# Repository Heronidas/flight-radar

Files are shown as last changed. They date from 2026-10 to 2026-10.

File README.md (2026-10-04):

# Flight Radar

ESP32 desk flight radar. A round GC9A01 display shows aircraft around a fixed location, a small SSD1306 OLED shows details of the selected aircraft, and a rotary encoder controls zoom, selection and OLED pages.

Aircraft positions come from the OpenSky Network API, aircraft types from hexdb.io.

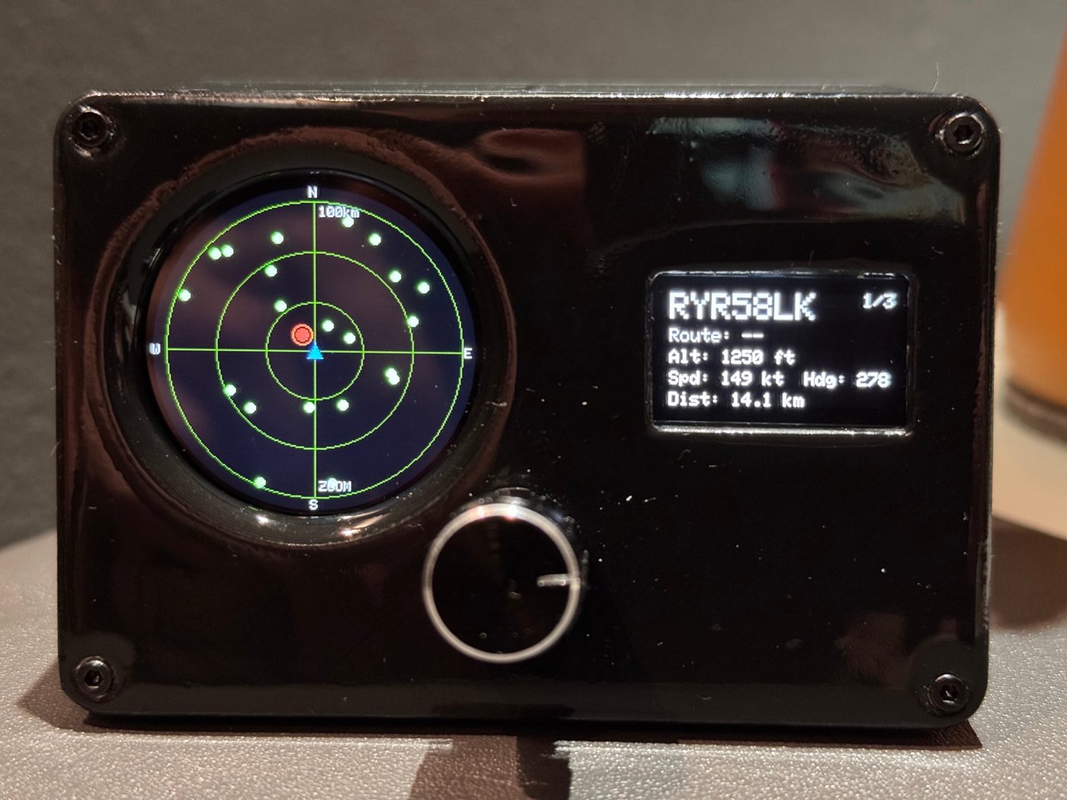
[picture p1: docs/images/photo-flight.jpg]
Flight page

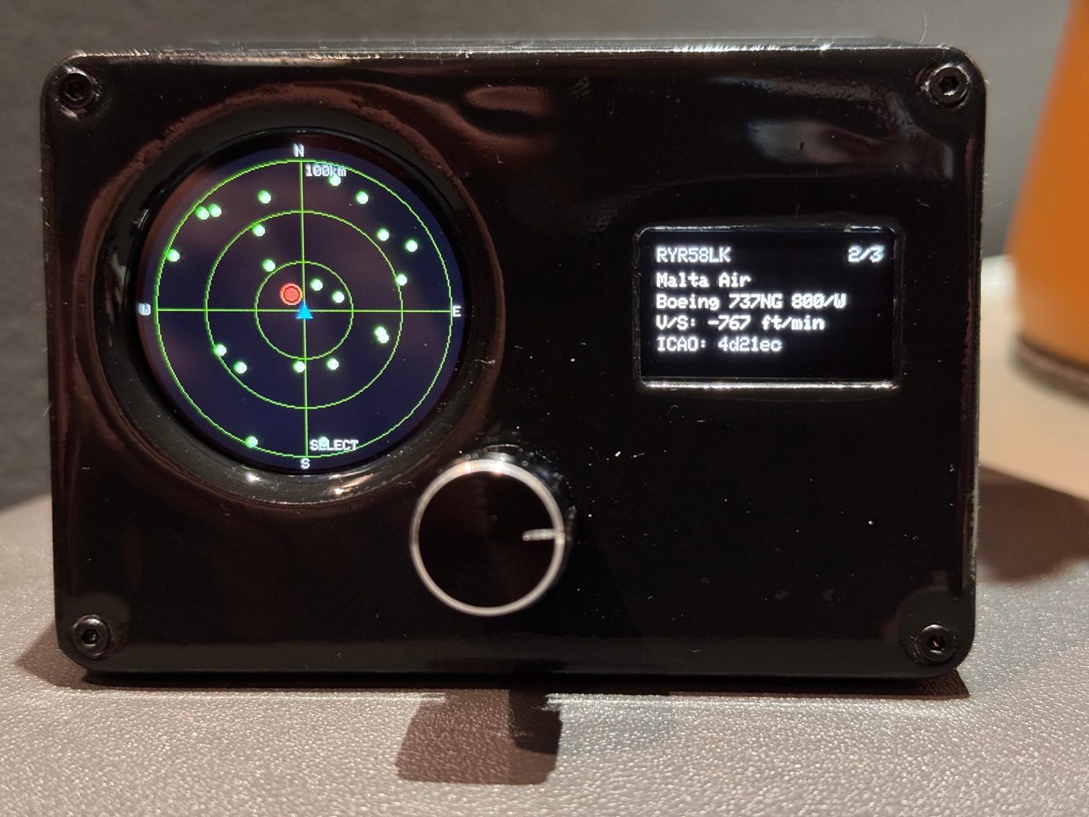
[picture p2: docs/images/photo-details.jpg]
Details page


## Hardware

- ESP32 DevKit (38 pin)
- GC9A01 1.28" round display, 240x240 (SPI)
- SSD1306 0.96" OLED, 128x64 (I2C, address 0x3C)
- EC11 rotary encoder with push button
- Regulated 5 V supply, at least 1 A
- Adhesive anti-slip pads, 10 mm diameter (underside)
- 4 × M2×8 screws and 4 × M2 heat-set inserts (case)

## Wiring

All parts run at 3.3 V. Power is fed directly to the ESP32 `5V` and `GND` pins; the enclosure has a snug cable pass-through. Disconnect the supply while flashing over USB.

| Part | Part pin | ESP32 pin |
|---|---|---|
| GC9A01 | VCC / GND | 3V3 / GND |
| | SCL (SCK) | GPIO18 |
| | SDA (MOSI) | GPIO23 |
| | CS | GPIO15 |
| | DC | GPIO2 |
| | RES | GPIO4 |
| | BLK | 3V3 |
| SSD1306 | VCC / GND | 3V3 / GND |
| | SDA | GPIO21 |
| | SCL | GPIO22 |
| EC11 | + / GND | 3V3 / GND |
| | CLK | GPIO25 |
| | DT | GPIO26 |
| | SW | GPIO27 |
| Power supply | +5 V / GND | 5V / GND |

GPIO2 and GPIO15 are strapping pins. If an upload fails, disconnect both wires briefly.

## Case

3D-printable enclosure: [`case/Flightradar_case.stl`](case/Flightradar_case.stl). Needed for the case:

- 4 × M2×8 screws
- 4 × M2 heat-set inserts
- Adhesive anti-slip pads, 10 mm diameter (optional, room on the underside)

Power: 5 V directly to the ESP32 `5V` and `GND` pins, with a snug cable pass-through.

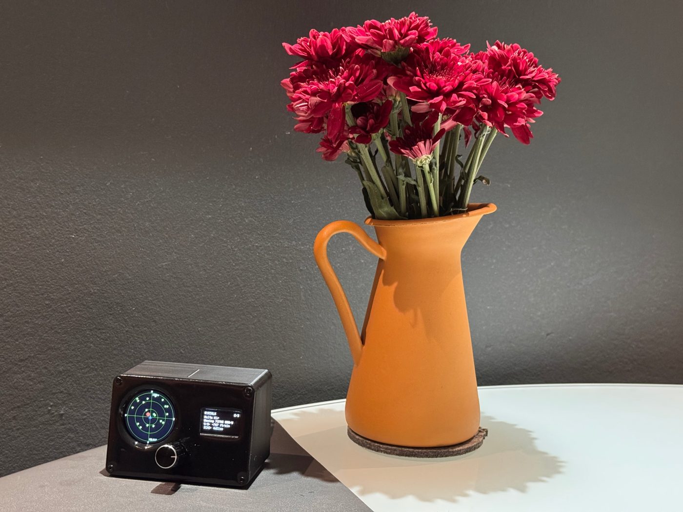
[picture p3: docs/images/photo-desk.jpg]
Finished device


## Setup

1. Install the ESP32 board package and select **ESP32 Dev Module**.
2. Install the libraries *Adafruit GFX Library*, *Adafruit SSD1306*, *GFX Library for Arduino* (by Moon On Our Nation) and *ArduinoJson*.
3. Upload `flight_radar/flight_radar.ino`. Nothing needs to be edited in the sketch.
4. On first start the device opens the WiFi **FlightRadar-Setup** (no password). Connect with a phone or PC and open `http://192.168.4.1`.
5. Select the WiFi network, enter the password and save. Only the WiFi is required. The device restarts and connects.
6. Open `http://flightradar.local/` (or the IP shown on the small display) and enter latitude, longitude, the OpenSky client ID and secret, and an OTA password. Until coordinates are set, the displays ask for them.

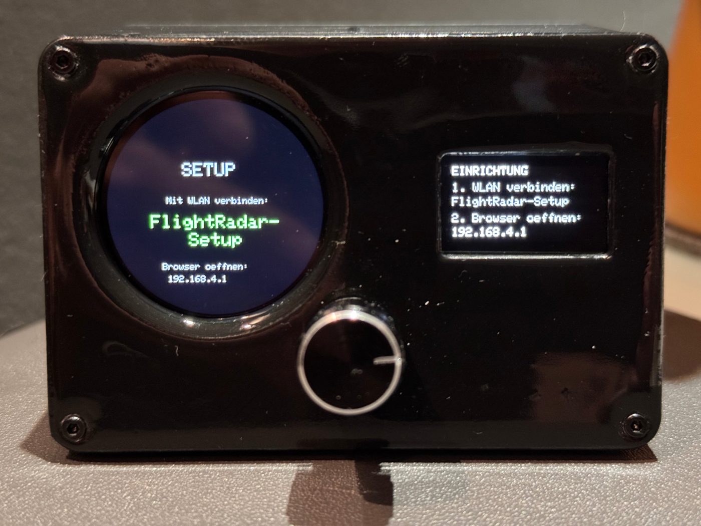
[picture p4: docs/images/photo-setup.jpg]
Setup screen


## OpenSky API

Aircraft data comes from the [OpenSky Network](https://opensky-network.org). Credentials are optional but recommended: anonymous access is limited to 400 credits per day, accounts get 4,000.

1. Create a free account at [opensky-network.org](https://opensky-network.org).
2. Open the [Account page](https://opensky-network.org/my-opensky/account) and create a new API client.
3. Copy the `client_id` and `client_secret` and paste them into the setup page.

Latitude and longitude: long-press the location in Google Maps, the coordinates appear at the top.

To change settings later, hold the encoder while powering on, or open `http://flightradar.local/` in the home network. Settings are stored in flash. If the saved WiFi cannot be reached, the setup portal opens and the device restarts after 10 minutes to try again.

## Updates (OTA)

Set an OTA password (at least 6 characters) on the setup page. Without a password, OTA is disabled. The first OTA-capable firmware must be flashed over USB.

- Arduino IDE: select the network port `flightradar` under *Tools > Port*, upload as usual and enter the OTA password.
- Browser: open `http://flightradar.local/update`, log in as `admin` with the OTA password and upload the `.bin` exported with *Sketch > Export Compiled Binary*.

If the sketch does not fit the update partition, select *Tools > Partition Scheme > Minimal SPIFFS (1.9MB APP with OTA)* and flash once over USB.

## Binaries

GitHub Actions compiles the sketch on every push (ESP32 Dev Module, partition scheme *Minimal SPIFFS*). The binaries are attached to the workflow run. Pushing a tag such as `v1.0.0` publishes them as a release:

- `*.merged.bin`: complete image for the first flash over USB (write at offset 0x0 with esptool or a browser flasher)
- `flight_radar.ino.bin`: application only, for OTA updates

## Controls

| Action | Effect |
|---|---|
| Turn (ZOOM) | Range: 10, 25, 50, 100 or 200 km |
| Short press | Next OLED page (1/3, 2/3, 3/3) |
| Turn (SELECT) | Select an aircraft (red) |
| Long press (~1 s) | Switch between ZOOM and SELECT |
| No input for 5 min | Screensaver: radar sweep with the aircraft in range, small display off. Any input wakes it. |
| Hold while powering on | Opens the setup portal |

The selection stays on the same aircraft between updates. Data is polled every 30 s and backs off for 3 minutes on HTTP 429.

## Notes

- The setup page and some OLED labels are in German.

## Guides

- [Guide (English)](docs/Flight_Radar_Guide_EN.pdf)
- [Anleitung (Deutsch)](docs/Flugradar_Anleitung_DE.pdf)

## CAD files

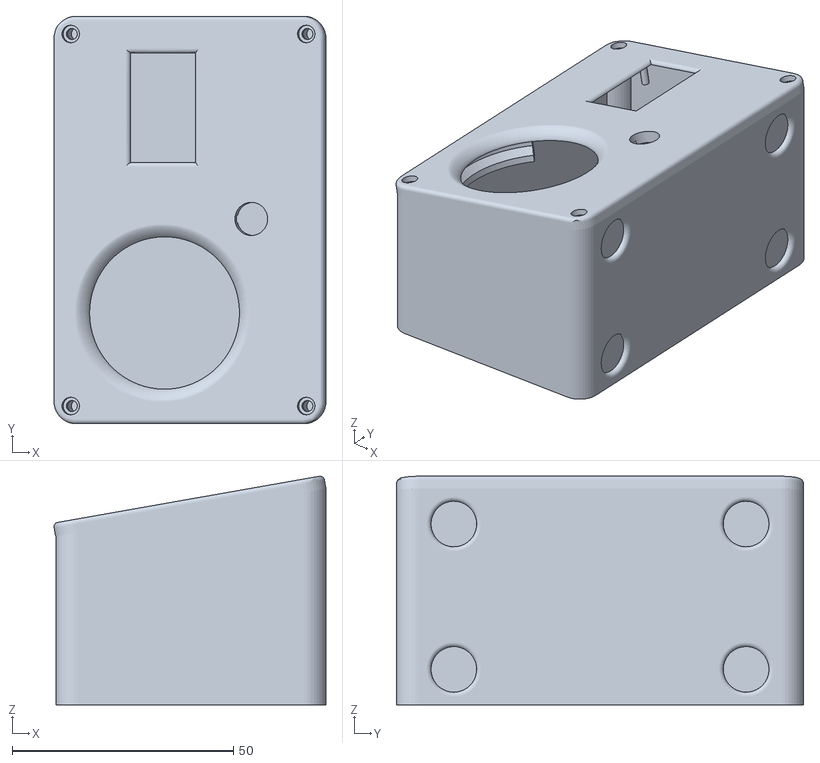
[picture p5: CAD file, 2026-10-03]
case/Flightradar_case.stl
61.4 x 92.0 x 51.6

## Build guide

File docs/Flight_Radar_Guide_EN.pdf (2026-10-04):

# Flight Radar – Operation

The device shows aircraft in the surrounding area. The round display is the radar; the small display shows details of the selected aircraft. Power on: connect the 5 V power supply. The radar appears after about 30 seconds.

### Controls (rotary encoder)

Action | Effect
Turn (display shows ZOOM) | Change range: 10, 25, 50, 100 or 200 km
Short press | Next page on the small display (1/3, 2/3, 3/3, then back to 1/3)
Turn (display shows SELECT) | Select an aircraft. The selected aircraft is marked red and its data appears on the small display.
Long press (about 1 second) | Switch between ZOOM and SELECT (shown at the bottom of the radar)
No input for 5 minutes | Screensaver (radar animation). Turning or pressing the encoder ends it.

### Procedure: selecting an aircraft

1. Press and hold the encoder – the bottom of the radar shows SELECT.
2. Turn the encoder until the desired aircraft is red.
3. If needed, press the encoder briefly to see more data.
The selection stays on the same aircraft between data updates.

### Display

Radar (round display) | Meaning
Blue triangle | Own location (center)
Green dot | Aircraft
Red dot with ring | Selected aircraft
Rings / number at top | Distance; the number applies to the outer ring
N, E, S, W | North, east, south, west
Small display | Content
Page 1/3 | Callsign, route (ICAO airports), altitude (ft), speed (kt), heading, distance
Page 2/3 | Operator, manufacturer and type, climb/descent rate (ft/min), ICAO address
Page 3/3 | IP address, aircraft within range and within 200 km, nearest aircraft, age of data

### Setup (first start, new WiFi or location)

1. On first start both displays show SETUP. To open setup later, hold the encoder pressed while powering on.
2. Connect a phone or PC to the WiFi FlightRadar-Setup (no password). Open 192.168.4.1 in the browser.

### 3. Select the WiFi network, enter the password and save. Only the WiFi is required. Enter

latitude/longitude and the OpenSky credentials (client ID, secret) later at flightradar.local.
4. Tap Save. The device restarts and shows the radar.
In the home network the page is also available at flightradar.local (or at the IP address on page 3/3).

### Notes

- Data updates every 30 seconds, so the dots move in steps. “No traffic” means no aircraft within the radius: select a larger range.
- If the device does not respond: unplug the power supply, wait 10 seconds, plug it in again. 1 ft = 0.30 m, 1 kt = 1.85 km/h. WiFi is required.

# ESP32 Pinout

ESP32 DevKit (38 pin, AZ-Delivery). Run all components at 3.3 V. Disconnect the ESP32 from power while wiring.
Component | Component pin | ESP32 pin | Done
Round display GC9A01 (SPI) | VCC | 3V3
| GND | GND
| SCL (SCK) | GPIO18
| SDA (MOSI) | GPIO23
| CS | GPIO15
| DC | GPIO2
| RES | GPIO4
| BLK | 3V3
OLED SSD1306 (I2C, 0x3C) | VCC | 3V3
| GND | GND
| SDA | GPIO21
| SCL | GPIO22
Rotary encoder EC11 | + | 3V3
| GND | GND
| CLK | GPIO25
| DT | GPIO26
| SW | GPIO27
Power supply 5 V DC | +5 V | 5V
| GND | GND

### Check by GPIO

GPIO | 2 | 4 | 15 | 18 | 21 | 22 | 23 | 25 | 26 | 27
Function | DC | RES | CS | SCK | SDA OLED | SCL OLED | MOSI | CLK | DT | SW

Used: GPIO 2, 4, 15, 18, 21, 22, 23, 25, 26, 27. The round display and the OLED share no pins.

### Firmware update (OTA)

1. Set an OTA password (at least 6 characters) on the setup page. Without a password, updates are disabled.
2. Arduino IDE: select the network port flightradar under Tools > Port, upload and enter the OTA password.
3. Or open flightradar.local/update in a browser (user admin, password = OTA password) and upload the .bin file (Sketch > Export Compiled Binary).
4. The small display shows the progress, then the device restarts.
The first OTA-capable firmware must be flashed over USB. If the sketch does not fit the update partition, select Tools > Partition Scheme > Minimal SPIFFS (1.9MB APP with OTA).

### Notes

- Power: regulated 5 V supply (at least 1 A) to the 5V and GND pins of the ESP32. Disconnect it while flashing over USB.
- Underside: space for adhesive anti-slip pads, 10 mm diameter.
- GPIO2 (DC) and GPIO15 (CS) are strapping pins. If the upload fails, briefly disconnect both wires.
- BLK is tied to 3V3 (GPIO21 is used for the OLED SDA).
- OLED stays dark and the monitor prints “SSD1306 init failed”: check SDA/SCL, change 0x3C to 0x3D in the sketch.
- If one detent of the encoder skips two steps: in handleEncoder() change the threshold 4 to 2.
- Settings are entered on the setup page; nothing to edit in the sketch. Serial Monitor: 115200 baud.

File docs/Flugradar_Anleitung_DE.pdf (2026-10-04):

# Flugradar – Bedienung

Das Gerät zeigt Flugzeuge in der Umgebung. Das runde Display ist das Radar, das kleine Display zeigt Details zum ausgewählten Flugzeug. Einschalten: 5-V-Netzteil anschließen, nach ca. 30 Sekunden erscheint das Radar.

### Bedienung mit dem Drehregler

Aktion | Wirkung
Drehen (Anzeige ZOOM) | Radius ändern: 10, 25, 50, 100 oder 200 km
Kurz drücken | Nächste Seite auf dem kleinen Display (1/3, 2/3, 3/3, dann wieder 1/3)
Drehen (Anzeige SELECT) | Flugzeug auswählen. Das ausgewählte Flugzeug ist rot markiert, seine Daten erscheinen auf dem kleinen Display.
Lang drücken (ca. 1 Sekunde) | Wechsel zwischen ZOOM und SELECT (Anzeige unten im Radar)
5 Minuten keine Eingabe | Bildschirmschoner (Radar-Animation). Knopf drehen oder drücken beendet ihn.

### Ablauf: Flugzeug auswählen

1. Regler lang drücken – unten steht SELECT.
2. Regler drehen, bis das gewünschte Flugzeug rot ist.
3. Bei Bedarf Regler kurz drücken, um weitere Daten zu sehen.
Die Auswahl bleibt bei der automatischen Aktualisierung auf demselben Flugzeug.

### Anzeige

Radar (rundes Display) | Bedeutung
Blaues Dreieck | Eigener Standort (Mitte)
Grüner Punkt | Flugzeug
Roter Punkt mit Ring | Ausgewähltes Flugzeug
Ringe / Zahl oben | Entfernung; die Zahl gilt für den äußeren Ring
N, E, S, W | Norden, Osten, Süden, Westen
Kleines Display | Inhalt
Seite 1/3 | Flugnummer, Route, Höhe (ft), Tempo (kt), Kurs, Entfernung
Seite 2/3 | Betreiber, Hersteller und Typ, Steig-/Sinkrate (ft/min), ICAO-Kennung
Seite 3/3 | IP-Adresse, Anzahl Flugzeuge im Radius und im Umkreis von 200 km, nächstes Flugzeug, Alter der Daten

### Einrichtung (Erststart, neues WLAN oder neuer Standort)

### 1. Beim ersten Start zeigen beide Displays SETUP bzw. EINRICHTUNG. Später öffnet man die

Einrichtung, indem man beim Einschalten den Regler gedrückt hält.

### 2. Handy oder PC mit dem WLAN FlightRadar-Setup verbinden (ohne Passwort). Im Browser

192.168.4.1 aufrufen.
3. WLAN-Netzwerk auswählen, Passwort eingeben, speichern. Nur das WLAN ist Pflicht. Breiten-/Längengrad und OpenSky-Zugang (Client-ID, Secret) später unter flightradar.local eintragen.
4. Speichern antippen. Das Gerät startet neu und zeigt das Radar.
Im Heimnetz ist die Seite auch unter flightradar.local erreichbar (oder über die IP-Adresse auf Seite 3/3).

### Hinweise

- Die Daten werden alle 30 Sekunden aktualisiert, die Punkte bewegen sich daher in Schritten. Steht „No traffic“ auf dem kleinen Display, ist kein Flugzeug im Radius: größeren Radius wählen.
- Reagiert das Gerät nicht: Netzteil abziehen, 10 Sekunden warten, wieder anschließen. 1 ft = 0,30 m, 1 kt = 1,85 km/h. Das Gerät benötigt WLAN.

# Pinbelegung ESP32

ESP32 DevKit (38 Pin, AZ-Delivery). Alle Bauteile mit 3,3 V betreiben. Beim Verkabeln den ESP32 vom Strom trennen.
Bauteil | Pin am Bauteil | Pin am ESP32 | Fertig
Rundes Display GC9A01 (SPI) | VCC | 3V3
| GND | GND
| SCL (SCK) | GPIO18
| SDA (MOSI) | GPIO23
| CS | GPIO15
| DC | GPIO2
| RES | GPIO4
| BLK | 3V3
OLED SSD1306 (I2C, 0x3C) | VCC | 3V3
| GND | GND
| SDA | GPIO21
| SCL | GPIO22
Drehregler EC11 | + | 3V3
| GND | GND
| CLK | GPIO25
| DT | GPIO26
| SW | GPIO27
Stromversorgung 5 V DC | +5 V | 5V
| GND | GND

### Kontrolle nach GPIO

GPIO | 2 | 4 | 15 | 18 | 21 | 22 | 23 | 25 | 26 | 27
Funktion | DC | RES | CS | SCK | SDA OLED | SCL OLED | MOSI | CLK | DT | SW

Belegt: GPIO 2, 4, 15, 18, 21, 22, 23, 25, 26, 27. Display-Anschlüsse und OLED teilen keine Pins.

### Firmware-Update (OTA)

1. Auf der Einrichtungsseite ein OTA-Passwort (mindestens 6 Zeichen) setzen. Ohne Passwort sind Updates ausgeschaltet.
2. Arduino IDE: unter Werkzeuge > Port den Netzwerk-Port flightradar wählen, hochladen und das OTA-Passwort eingeben.
3. Oder im Browser flightradar.local/update öffnen (Benutzer admin, Passwort = OTA-Passwort) und die .bin-Datei hochladen (Sketch > Kompilierte Binärdatei exportieren).
4. Das kleine Display zeigt den Fortschritt, danach startet das Gerät neu.
Die erste OTA-fähige Firmware muss per USB geflasht werden. Passt der Sketch nicht in den Update-Speicher: Werkzeuge > Partition Scheme > Minimal SPIFFS (1.9MB APP with OTA).

### Hinweise

- Stromversorgung: stabilisiertes 5-V-Netzteil (mind. 1 A) an 5V und GND. Beim USB-Flashen abziehen.
- Unterseite: Platz für rutschfeste Klebepads, Durchmesser 10 mm.
- GPIO2 (DC) und GPIO15 (CS) sind Strapping-Pins. Bricht der Upload ab, beide Leitungen kurz abziehen.
- BLK liegt fest an 3V3 (GPIO21 ist für SDA des OLED belegt).
- OLED bleibt dunkel, Monitor meldet „SSD1306 init failed“: SDA/SCL prüfen, im Sketch 0x3C auf 0x3D ändern.
- Springt ein Rastpunkt am Regler um zwei Stufen: in handleEncoder() die Schwelle 4 auf 2 setzen.
- Einstellungen nur über die Einrichtungsseite. Serial Monitor: 115200 Baud.

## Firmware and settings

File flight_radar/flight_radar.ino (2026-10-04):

/*
  ESP32 flight radar: GC9A01 round display, SSD1306 OLED, EC11 encoder.
  Data: OpenSky Network API, type lookup via hexdb.io.
  Settings are entered on the setup page (AP "FlightRadar-Setup" or http://flightradar.local/).
*/

#include <WiFi.h>
#include <WiFiClientSecure.h>
#include <HTTPClient.h>
#include <WebServer.h>
#include <ESPmDNS.h>
#include <Preferences.h>
#include <ArduinoOTA.h>
#include <Update.h>
#include <ArduinoJson.h>
#include <Wire.h>
#include <Adafruit_GFX.h>
#include <Adafruit_SSD1306.h>
#include <Arduino_GFX_Library.h>
#include <math.h>

const char *SETUP_AP_NAME   = "FlightRadar-Setup";
const char *MDNS_NAME = "flightradar";

const unsigned long POLL_INTERVAL_MS   = 30000;
const unsigned long BACKOFF_429_MS     = 180000;
const unsigned long LONG_PRESS_MS      = 700;
const unsigned long WIFI_TIMEOUT_MS    = 20000;
const unsigned long PORTAL_TIMEOUT_MS  = 600000;
const unsigned long SCREENSAVER_MS     = 300000;

#define TFT_CS   15
#define TFT_DC   2
#define TFT_RST  4
#define TFT_SCK  18
#define TFT_MOSI 23

#define ENC_CLK 25
#define ENC_DT  26
#define ENC_SW  27

WiFiClientSecure secureClient;

Adafruit_SSD1306 infoDisplay(128, 64, &Wire, -1);

Arduino_DataBus *bus = new Arduino_ESP32SPI(
    TFT_DC, TFT_CS, TFT_SCK, TFT_MOSI, GFX_NOT_DEFINED, VSPI);
Arduino_GFX *radar = new Arduino_GC9A01(bus, TFT_RST, 0, true);

#define RADAR_W 240
#define RADAR_H 240
#define RADAR_CX 120
#define RADAR_CY 120
#define RADAR_MAX_R 110

uint16_t COL_BG, COL_RING, COL_TEXT, COL_PLANE, COL_SELECTED, COL_HOME;

struct Plane {
  char icao24[7];
  char callsign[9];
  float altitude_m;
  float velocity_ms;
  float heading_deg;
  float vrate_ms;
  float distance_km;
  float bearing_deg;
};

#define MAX_PLANES 100
Plane planes[MAX_PLANES];
int planeCount = 0;
int visibleCount = 0;

enum Mode { MODE_ZOOM, MODE_SELECT };
Mode currentMode = MODE_ZOOM;

const int RANGE_PRESETS[] = {10, 25, 50, 100, 200};
const int NUM_RANGES = 5;
int rangeIndex = 3;

int selectedIndex = 0;
String selectedIcao = "";
bool followNearest = true;

int infoPage = 0;

unsigned long pollIntervalMs = POLL_INTERVAL_MS;
unsigned long lastFetchOkMs = 0;
int lastHttpCode = 0;

Preferences prefs;
String cfgSsid, cfgPass, cfgClientId, cfgClientSecret, cfgOtaPass;
double cfgLat = 0, cfgLon = 0;

void loadConfig() {
  prefs.begin("radar", true);
  cfgSsid         = prefs.getString("ssid", "");
  cfgPass         = prefs.getString("pass", "");
  cfgClientId     = prefs.getString("cid", "");
  cfgClientSecret = prefs.getString("csec", "");
  cfgOtaPass      = prefs.getString("ota", "");
  cfgLat          = prefs.getDouble("lat", 0);
  cfgLon          = prefs.getDouble("lon", 0);
  int r           = prefs.getInt("range", 3);
  rangeIndex      = (r < 0 || r >= NUM_RANGES) ? 3 : r;
  prefs.end();
}

bool hasConfig() {
  return cfgSsid.length() > 0;
}

bool hasCoords() {
  return !(cfgLat == 0 && cfgLon == 0);
}

volatile int encoderDelta = 0;
volatile uint8_t encoderStateHistory = 0;
volatile int8_t encoderAccum = 0;

const int8_t QUADRATURE_TABLE[16] = {
   0, -1,  1,  0,
   1,  0,  0, -1,
  -1,  0,  0,  1,
   0,  1, -1,  0
};

void IRAM_ATTR handleEncoder() {
  encoderStateHistory <<= 2;
  encoderStateHistory |= (digitalRead(ENC_CLK) << 1) | digitalRead(ENC_DT);
  encoderStateHistory &= 0x0F;

  int8_t change = QUADRATURE_TABLE[encoderStateHistory];
  if (change != 0) {
    encoderAccum += change;
    if (encoderAccum >= 4) {
      encoderDelta++;
      encoderAccum = 0;
    } else if (encoderAccum <= -4) {
      encoderDelta--;
      encoderAccum = 0;
    }
  }
}

bool btnActivity = false;
unsigned long lastActivityMs = 0;
bool btnWasDown = false;
bool longPressDone = false;
unsigned long btnDownMs = 0;
unsigned long btnEdgeMs = 0;

bool checkButton() {
  unsigned long now = millis();
  bool down = (digitalRead(ENC_SW) == LOW);
  bool changed = false;

  if (down != btnWasDown && now - btnEdgeMs > 25) {
    btnEdgeMs = now;
    btnWasDown = down;
    btnActivity = true;
    if (down) {
      btnDownMs = now;
      longPressDone = false;
    } else if (!longPressDone) {
      infoPage = (infoPage + 1) % 3;
      changed = true;
    }
  }

  if (btnWasDown && !longPressDone && now - btnDownMs > LONG_PRESS_MS) {
    longPressDone = true;
    currentMode = (currentMode == MODE_ZOOM) ? MODE_SELECT : MODE_ZOOM;
    changed = true;
  }
  return changed;
}

double toRad(double deg) { return deg * M_PI / 180.0; }
double toDeg(double rad) { return rad * 180.0 / M_PI; }

float distanceKm(double lat1, double lon1, double lat2, double lon2) {
  double R = 6371.0;
  double dLat = toRad(lat2 - lat1);
  double dLon = toRad(lon2 - lon1);
  double a = sin(dLat / 2) * sin(dLat / 2) +
             cos(toRad(lat1)) * cos(toRad(lat2)) *
             sin(dLon / 2) * sin(dLon / 2);
  double c = 2 * atan2(sqrt(a), sqrt(1 - a));
  return (float)(R * c);
}

float bearingDeg(double lat1, double lon1, double lat2, double lon2) {
  double y = sin(toRad(lon2 - lon1)) * cos(toRad(lat2));
  double x = cos(toRad(lat1)) * sin(toRad(lat2)) -
             sin(toRad(lat1)) * cos(toRad(lat2)) * cos(toRad(lon2 - lon1));
  double brng = toDeg(atan2(y, x));
  return (float)fmod((brng + 360.0), 360.0);
}

void syncSelection() {
  if (planeCount == 0) {
    selectedIndex = 0;
    return;
  }
  if (followNearest) {
    selectedIndex = 0;
  } else {
    int found = -1;
    for (int i = 0; i < planeCount; i++) {
      if (selectedIcao == planes[i].icao24) { found = i; break; }
    }
    selectedIndex = (found >= 0) ? found : 0;
  }
  if (selectedIndex >= visibleCount) selectedIndex = 0;
  selectedIcao = planes[selectedIndex].icao24;
}

void updateVisible() {
  int rangeKm = RANGE_PRESETS[rangeIndex];
  visibleCount = 0;
  while (visibleCount < planeCount && planes[visibleCount].distance_km <= rangeKm) {
    visibleCount++;
  }
  syncSelection();
}

String metaIcao24;
String metaType;
String metaManufacturer;
String metaOperator;
bool metaValid = false;
bool metaLookupFailed = false;

void lookupAircraftType(const String &icao24) {
  if (icao24.length() == 0) return;
  if (icao24 == metaIcao24 && (metaValid || metaLookupFailed)) return;
  if (WiFi.status() != WL_CONNECTED) return;

  HTTPClient http;
  http.setReuse(false);
  http.begin(secureClient, "https://hexdb.io/api/v1/aircraft/" + icao24);
  http.setTimeout(5000);
  int code = http.GET();

  metaIcao24 = icao24;
  metaValid = false;
  metaLookupFailed = true;

  if (code == 200) {
    String payload = http.getString();
    StaticJsonDocument<512> doc;
    if (!deserializeJson(doc, payload)) {
      if (doc.containsKey("Manufacturer")) {
        metaManufacturer = doc["Manufacturer"].as<String>();
        metaType = doc["Type"].as<String>();
        metaOperator = doc["RegisteredOwners"] | "";
        metaValid = true;
        metaLookupFailed = false;
      }
    }
  }
  http.end();
}

char routeCallsign[9] = "";
char routeText[24] = "";
bool routeDone = false;

struct AirportCode { char icao[5]; char iata[4]; };
AirportCode airportCache[12];
int airportCacheNext = 0;

const char *iataFor(const char *icao) {
  for (auto &a : airportCache) {
    if (strcmp(a.icao, icao) == 0) return a.iata;
  }
  AirportCode &slot = airportCache[airportCacheNext];
  airportCacheNext = (airportCacheNext + 1) % 12;
  strlcpy(slot.icao, icao, sizeof(slot.icao));
  strlcpy(slot.iata, icao + 1, sizeof(slot.iata));

  HTTPClient http;
  http.setReuse(false);
  http.begin(secureClient, "https://hexdb.io/api/v1/airport/icao/" + String(icao));
  http.setTimeout(5000);
  if (http.GET() == 200) {
    StaticJsonDocument<384> doc;
    if (!deserializeJson(doc, http.getString())) {
      const char *iata = doc["iata"] | "";
      if (iata[0]) strlcpy(slot.iata, iata, sizeof(slot.iata));
    }
  }
  http.end();
  return slot.iata;
}

void lookupRoute(const char *callsign) {
  if (!callsign[0]) return;
  if (routeDone && strcmp(callsign, routeCallsign) == 0) return;
  if (WiFi.status() != WL_CONNECTED) return;

  strlcpy(routeCallsign, callsign, sizeof(routeCallsign));
  routeText[0] = 0;
  routeDone = true;

  HTTPClient http;
  http.setReuse(false);
  http.begin(secureClient, "https://hexdb.io/api/v1/route/icao/" + String(callsign));
  http.setTimeout(5000);
  char icaoRoute[24] = "";
  if (http.GET() == 200) {
    StaticJsonDocument<256> doc;
    if (!deserializeJson(doc, http.getString())) {
      strlcpy(icaoRoute, doc["route"] | "", sizeof(icaoRoute));
    }
  }
  http.end();

  char *save;
  for (char *code = strtok_r(icaoRoute, "-", &save); code; code = strtok_r(nullptr, "-", &save)) {
    if (strlen(code) != 4) continue;
    if (routeText[0]) strlcat(routeText, ">", sizeof(routeText));
    strlcat(routeText, iataFor(code), sizeof(routeText));
  }
}

String openskyToken;
unsigned long tokenExpiresAtMs = 0;

String getOpenSkyToken() {
  if (cfgClientId.length() == 0 || cfgClientSecret.length() == 0) return "";
  if (openskyToken.length() > 0 && millis() < tokenExpiresAtMs) {
    return openskyToken;
  }
  if (WiFi.status() != WL_CONNECTED) return "";

  HTTPClient http;
  http.setReuse(false);
  http.begin(secureClient, "https://auth.opensky-network.org/auth/realms/opensky-network/protocol/openid-connect/token");
  http.addHeader("Content-Type", "application/x-www-form-urlencoded");

  String body = "grant_type=client_credentials&client_id=" + cfgClientId +
                "&client_secret=" + cfgClientSecret;

  int code = http.POST(body);
  if (code == 200) {
    String payload = http.getString();
    StaticJsonDocument<1024> doc;
    if (!deserializeJson(doc, payload)) {
      openskyToken = doc["access_token"].as<String>();
      long expiresIn = doc["expires_in"] | 1800;
      if (expiresIn < 120) expiresIn = 120;
      tokenExpiresAtMs = millis() + (unsigned long)(expiresIn - 60) * 1000UL;
      Serial.println("OpenSky token refreshed OK");
    }
  } else {
    Serial.print("Token fetch failed, HTTP code: ");
    Serial.println(code);
    openskyToken = "";
  }
  http.end();
  return openskyToken;
}

int doStatesRequest(HTTPClient &http, const String &url, const String &token) {
  http.setReuse(false);
  http.useHTTP10(true);
  http.begin(secureClient, url);
  http.setTimeout(15000);
  if (token.length() > 0) {
    http.addHeader("Authorization", "Bearer " + token);
  }
  return http.GET();
}

void fetchPlanes() {
  if (WiFi.status() != WL_CONNECTED) return;

  int rangeKm = RANGE_PRESETS[NUM_RANGES - 1];
  double latPad = rangeKm / 111.0;
  double lonPad = rangeKm / (111.0 * cos(toRad(cfgLat)) + 0.0001);

  String url = "https://opensky-network.org/api/states/all?lamin=" + String(cfgLat - latPad, 4) +
               "&lomin=" + String(cfgLon - lonPad, 4) +
               "&lamax=" + String(cfgLat + latPad, 4) +
               "&lomax=" + String(cfgLon + lonPad, 4);

  String token = getOpenSkyToken();

  HTTPClient http;
  int code = doStatesRequest(http, url, token);
  Serial.print("States fetch HTTP code: ");
  Serial.println(code);
  Serial.print("Free heap: ");
  Serial.println(ESP.getFreeHeap());

  lastHttpCode = code;

  if (code == 429) {
    Serial.println("Rate limited, backing off");
    pollIntervalMs = BACKOFF_429_MS;
    http.end();
    return;
  }

  if (code != 200) {
    http.end();
    delay(2000);
    code = doStatesRequest(http, url, token);
    Serial.print("Retry HTTP code: ");
    Serial.println(code);
    lastHttpCode = code;
  }

  if (code == 200) {
    pollIntervalMs = POLL_INTERVAL_MS;

    String body = http.getString();
    Serial.print("Payload bytes: ");
    Serial.println(body.length());

    const char *cur = strstr(body.c_str(), "\"states\":");
    bool ok = cur != nullptr;
    planeCount = 0;
    if (ok) {
      cur = strchr(cur + 9, '[');
      if (cur) cur++;
      while (cur && planeCount < MAX_PLANES) {
        cur = strchr(cur, '[');
        if (!cur) break;
        const char *end = strchr(cur, ']');
        if (!end) break;
        StaticJsonDocument<1024> d;
        DeserializationError err = deserializeJson(d, cur, end - cur + 1);
        cur = end + 1;
        if (err) continue;
        JsonArray s = d.as<JsonArray>();
        if (s.size() < 12) continue;
        if (s[5].isNull() || s[6].isNull()) continue;
        if (s[8].as<bool>()) continue;

        Plane &p = planes[planeCount];
        strlcpy(p.icao24, s[0] | "", sizeof(p.icao24));
        strlcpy(p.callsign, s[1] | "", sizeof(p.callsign));
        for (int k = strlen(p.callsign) - 1; k >= 0 && p.callsign[k] == ' '; k--) p.callsign[k] = 0;
        if (!p.callsign[0]) strlcpy(p.callsign, p.icao24, sizeof(p.callsign));

        double plon = s[5].as<double>();
        double plat = s[6].as<double>();
        p.altitude_m = s[7].as<float>();
        p.velocity_ms = s[9].as<float>();
        p.heading_deg = s[10].as<float>();
        p.vrate_ms = s[11].as<float>();

        p.distance_km = distanceKm(cfgLat, cfgLon, plat, plon);
        p.bearing_deg = bearingDeg(cfgLat, cfgLon, plat, plon);

        if (p.distance_km > rangeKm) continue;
        planeCount++;
      }
    }
    body = String();

    if (ok) {
      for (int i = 1; i < planeCount; i++) {
        Plane key = planes[i];
        int j = i - 1;
        while (j >= 0 && planes[j].distance_km > key.distance_km) {
          planes[j + 1] = planes[j];
          j--;
        }
        planes[j + 1] = key;
      }

      lastFetchOkMs = millis();
      updateVisible();
      Serial.print("Planes in range: ");
      Serial.println(planeCount);
    } else {
      Serial.println("No states in response");
      lastHttpCode = -100;
    }
  }
  http.end();
}

void drawRadar() {
  radar->fillScreen(COL_BG);

  int rangeKm = RANGE_PRESETS[rangeIndex];

  for (int i = 1; i <= 3; i++) {
    int r = (RADAR_MAX_R * i) / 3;
    radar->drawCircle(RADAR_CX, RADAR_CY, r, COL_RING);
  }

  radar->drawLine(RADAR_CX, RADAR_CY - RADAR_MAX_R, RADAR_CX, RADAR_CY + RADAR_MAX_R, COL_RING);
  radar->drawLine(RADAR_CX - RADAR_MAX_R, RADAR_CY, RADAR_CX + RADAR_MAX_R, RADAR_CY, COL_RING);

  radar->setTextColor(COL_TEXT);
  radar->setTextSize(1);
  radar->setCursor(RADAR_CX - 3, RADAR_CY - RADAR_MAX_R - 10); radar->print("N");
  radar->setCursor(RADAR_CX + RADAR_MAX_R + 2, RADAR_CY - 3);  radar->print("E");
  radar->setCursor(RADAR_CX - 3, RADAR_CY + RADAR_MAX_R + 2);  radar->print("S");
  radar->setCursor(RADAR_CX - RADAR_MAX_R - 10, RADAR_CY - 3); radar->print("W");

  radar->setCursor(RADAR_CX + 4, RADAR_CY - RADAR_MAX_R + 4);
  radar->print(rangeKm);
  radar->print("km");

  radar->fillTriangle(RADAR_CX, RADAR_CY - 6, RADAR_CX - 5, RADAR_CY + 5,
                       RADAR_CX + 5, RADAR_CY + 5, COL_HOME);

  for (int i = 0; i < visibleCount; i++) {
    Plane &p = planes[i];
    float r = (p.distance_km / rangeKm) * RADAR_MAX_R;
    if (r > RADAR_MAX_R) continue;
    float rad = toRad(p.bearing_deg);
    int x = RADAR_CX + (int)(r * sin(rad));
    int y = RADAR_CY - (int)(r * cos(rad));

    bool isSelected = (i == selectedIndex);
    uint16_t col = isSelected ? COL_SELECTED : COL_PLANE;

    radar->fillCircle(x, y, isSelected ? 4 : 3, col);
    if (isSelected) {
      radar->drawCircle(x, y, 7, col);
    }
  }

  radar->setCursor(RADAR_CX + 4, RADAR_CY + RADAR_MAX_R - 12);
  radar->setTextColor(COL_TEXT);
  radar->print(currentMode == MODE_ZOOM ? "ZOOM" : "SELECT");
}

String clip(const String &s, size_t n) {
  return s.length() > n ? s.substring(0, n) : s;
}

void drawPageMark() {
  infoDisplay.setTextSize(1);
  infoDisplay.setCursor(110, 0);
  infoDisplay.print(infoPage + 1);
  infoDisplay.print("/3");
}

void drawDetails(Plane &p) {
  infoDisplay.setTextSize(1);
  infoDisplay.setCursor(0, 0);
  infoDisplay.print(p.callsign);
  drawPageMark();

  bool have = (metaIcao24 == p.icao24 && metaValid);

  infoDisplay.setCursor(0, 14);
  if (have) {
    infoDisplay.print(metaOperator.length() ? clip(metaOperator, 21) : String("Betreiber: --"));
  } else if (metaIcao24 == p.icao24 && metaLookupFailed) {
    infoDisplay.print("Betreiber: unbekannt");
  } else {
    infoDisplay.print("Suche...");
  }

  infoDisplay.setCursor(0, 26);
  if (have) infoDisplay.print(clip(metaManufacturer + " " + metaType, 21));

  int vs = (int)(p.vrate_ms * 196.85f);
  infoDisplay.setCursor(0, 38);
  infoDisplay.print("V/S: ");
  if (vs > 0) infoDisplay.print("+");
  infoDisplay.print(vs);
  infoDisplay.print(" ft/min");

  infoDisplay.setCursor(0, 50);
  infoDisplay.print("ICAO: ");
  infoDisplay.print(p.icao24);
}

void drawStats() {
  infoDisplay.setTextSize(1);
  infoDisplay.setCursor(0, 0);
  infoDisplay.print("IP ");
  infoDisplay.print(WiFi.localIP());
  drawPageMark();

  infoDisplay.setCursor(0, 14);
  infoDisplay.print("In ");
  infoDisplay.print(RANGE_PRESETS[rangeIndex]);
  infoDisplay.print(" km: ");
  infoDisplay.print(visibleCount);

  infoDisplay.setCursor(0, 26);
  infoDisplay.print("In ");
  infoDisplay.print(RANGE_PRESETS[NUM_RANGES - 1]);
  infoDisplay.print(" km: ");
  infoDisplay.print(planeCount);

  infoDisplay.setCursor(0, 38);
  if (planeCount > 0) {
    infoDisplay.print("Naechst: ");
    infoDisplay.print(planes[0].callsign);
  } else {
    infoDisplay.print("Kein Verkehr");
  }

  infoDisplay.setCursor(0, 50);
  infoDisplay.print("Update: ");
  if (lastFetchOkMs == 0) {
    infoDisplay.print("--");
  } else {
    infoDisplay.print((millis() - lastFetchOkMs) / 1000);
    infoDisplay.print(" s");
  }
}

void drawInfo() {
  infoDisplay.clearDisplay();
  infoDisplay.setTextColor(SSD1306_WHITE);

  if (infoPage == 2) {
    drawStats();
    infoDisplay.display();
    return;
  }

  if (visibleCount == 0) {
    infoDisplay.setTextSize(1);
    infoDisplay.setCursor(0, 0);
    if (lastHttpCode != 200 && lastHttpCode != 0) {
      infoDisplay.print("API Fehler ");
      infoDisplay.print(lastHttpCode);
    } else {
      infoDisplay.print("No traffic");
    }
    infoDisplay.setCursor(0, 14);
    infoDisplay.print("Range: ");
    infoDisplay.print(RANGE_PRESETS[rangeIndex]);
    infoDisplay.print(" km");
    infoDisplay.setCursor(0, 28);
    infoDisplay.print(cfgLat, 4);
    infoDisplay.setCursor(0, 40);
    infoDisplay.print(cfgLon, 4);
    drawPageMark();
    infoDisplay.display();
    return;
  }

  int idx = (selectedIndex < visibleCount) ? selectedIndex : 0;
  Plane &p = planes[idx];

  if (infoPage == 1) {
    drawDetails(p);
    infoDisplay.display();
    return;
  }

  float altFt = p.altitude_m * 3.28084f;
  float speedKt = p.velocity_ms * 1.94384f;

  infoDisplay.setTextSize(2);
  infoDisplay.setCursor(0, 0);
  infoDisplay.print(p.callsign);

  infoDisplay.setTextSize(1);
  infoDisplay.setCursor(0, 20);
  if (routeText[0] && strcmp(routeCallsign, p.callsign) == 0) infoDisplay.print(routeText);
  else infoDisplay.print("Route: --");

  infoDisplay.setCursor(0, 32);
  infoDisplay.print("Alt: ");
  infoDisplay.print((int)altFt);
  infoDisplay.print(" ft");

  infoDisplay.setCursor(0, 44);
  infoDisplay.print("Spd: ");
  infoDisplay.print((int)speedKt);
  infoDisplay.print(" kt  Hdg: ");
  infoDisplay.print((int)p.heading_deg);

  infoDisplay.setCursor(0, 56);
  infoDisplay.print("Dist: ");
  infoDisplay.print(p.distance_km, 1);
  infoDisplay.print(" km");

  drawPageMark();
  infoDisplay.display();
}

bool screensaverActive = false;
float sweepDeg = 0;
const int SWEEP_STEP = 3;
const int SWEEP_TRAIL = 10;
const int SWEEP_R = RADAR_MAX_R - 2;
const unsigned long BLIP_LIFE_MS = 3000;

struct Blip {
  int16_t x, y;
  unsigned long t;
  bool on;
};
Blip blips[24];
int blipNext = 0;

void drawSweepLine(float deg, uint16_t col) {
  float rad = toRad(deg);
  radar->drawLine(RADAR_CX, RADAR_CY, RADAR_CX + (int)(SWEEP_R * sin(rad)),
                  RADAR_CY - (int)(SWEEP_R * cos(rad)), col);
}
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
void loop() {
  server.handleClient();
  if (otaActive) ArduinoOTA.handle();

  if (!hasCoords()) {
    delay(20);
    return;
  }

  bool needsRedraw = checkButton();

  noInterrupts();
  int delta = encoderDelta;
  encoderDelta = 0;
  interrupts();

  bool activity = btnActivity || delta != 0;
  btnActivity = false;
  if (activity) lastActivityMs = millis();

  if (screensaverActive) {
    if (!activity) {
      if (millis() - lastPoll > pollIntervalMs) {
        if (WiFi.status() != WL_CONNECTED) WiFi.reconnect();
        fetchPlanes();
        lastPoll = millis();
      }
      stepScreensaver();
      delay(20);
      return;
    }
    stopScreensaver();
    if (btnWasDown) longPressDone = true;
    delta = 0;
    needsRedraw = true;
  } else if (millis() - lastActivityMs > SCREENSAVER_MS) {
    startScreensaver();
    return;
  }

  if (delta != 0) {
    if (currentMode == MODE_ZOOM) {
      rangeIndex += (delta > 0) ? 1 : -1;
      if (rangeIndex < 0) rangeIndex = 0;
      if (rangeIndex >= NUM_RANGES) rangeIndex = NUM_RANGES - 1;
      updateVisible();
    } else if (visibleCount > 0) {
      selectedIndex += (delta > 0) ? 1 : -1;
      if (selectedIndex < 0) selectedIndex = visibleCount - 1;
      if (selectedIndex >= visibleCount) selectedIndex = 0;
      selectedIcao = planes[selectedIndex].icao24;
      followNearest = false;
    }
    needsRedraw = true;
  }

  if (millis() - lastPoll > pollIntervalMs) {
    if (WiFi.status() != WL_CONNECTED) WiFi.reconnect();
    fetchPlanes();
    lastPoll = millis();
    needsRedraw = true;
  }

  if (needsRedraw) {
    if (visibleCount > 0) {
      int idx = (selectedIndex < visibleCount) ? selectedIndex : 0;
      if (infoPage == 0) lookupRoute(planes[idx].callsign);
      else if (infoPage == 1) lookupAircraftType(planes[idx].icao24);
    }
    drawRadar();
    drawInfo();
    lastInfoRedraw = millis();
  } else if (infoPage == 2 && millis() - lastInfoRedraw > 1000) {
    drawInfo();
    lastInfoRedraw = millis();
  }

  delay(20);
}

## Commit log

2026-10-03 Document 5 V power supply and anti-slip pads
2026-10-03 Show API error code and position when no traffic
    [flight_radar.ino]
2026-10-03 Remove DNS server, use fixed-size plane strings, trim comments
    [flight_radar.ino]
2026-10-03 Skip outer states bracket
    [flight_radar.ino]
2026-10-03 Swap button roles, add route lookup, rework flight page
    [flight_radar.ino]
2026-10-03 Add case STL and photos
    [Flightradar_case.stl]
2026-10-03 List case screws and inserts
2026-10-03 Case parts list in README
